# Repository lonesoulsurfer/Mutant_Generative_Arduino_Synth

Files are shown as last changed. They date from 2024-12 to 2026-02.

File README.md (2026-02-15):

# Mutant_Generative_Arduino_Synth



UPDATE: I have updated the Mutant code so it can be loaded using the most recent Mozzi Library.  You can find the code in the 'Mutant_Updated' file.  It works perfectly and there is no changes to the sounds etc.

 Meebleeps awesome Mutant Synth in modular format

First and foremost - I need to do a huge shoutout to MeeBleeps (https://github.com/Meebleeps/MeeBleeps-Mutant-Synth) who designed this amazing synth. I've designed a PCB and front panel to fit modular synths or you could use it as a stand alone synth if you wanted to.  You can power the synth used a voltage range from 9 to 12V's

You can find a step by step guide on my Instructables page on how to build your own - https://www.instructables.com/Mutant-Generative-Arduino-Synth/

I have also posted a video on my YouTube page - https://www.youtube.com/watch?v=L1Gzkz4_xpQ

The main goal with building this module is to create my own 'simple to build' modular synth. I wanted to keep everything as easy as possble with each module built with the following aims:

Can be powered by 9V (and 12V)
Easy to build with minimum components
Use Arduino to keep it simple (plus it helps to keep the components down and everything in tune)
Can fit into any modular synth Eurorck (include the ability to power the module via normal module power sources)
Has to sound great!
Lastly, it should be portable and be powered from a 9V battery

So what is the Mutant Synth? Well it's a generative synth based around a Arduino Nano and a handful of other components and produces a rich soundscape of sounds.

The synth voice is based around 2 saw oscillators that features:

Multiple tuning modes for the 2nd oscillator - off, detune, fifths & octaves up/down
Low pass filter with variable cutoff and resonance
Variable level ducking/sidechain effects
The display is a 8X8 LED matrix which allows you to visually see where each control level is at. This also includes a 16 step generative sequencer that mutates/evolves at defined rate depending on control inputs.

Variable sequence mutation probability & note-density
Sync input & output (Korg Volca compatible)
Note selection
Selectable scale quantization (Major, Minor, Pentatonic, Phrygian (GOA!), Octaves, Fifths)
16-step parameter-lock recording of synth parameters
Retrig (clone) button for different fills
Tap-tempo control

The Mozzi library used in the script is an older version which isn't a big deal but you will need to update IDE with an older version of Mozzie (1.1.2).  You can easily do this in IDE but if you are unsure how to do this then check out my Instruacable I published.



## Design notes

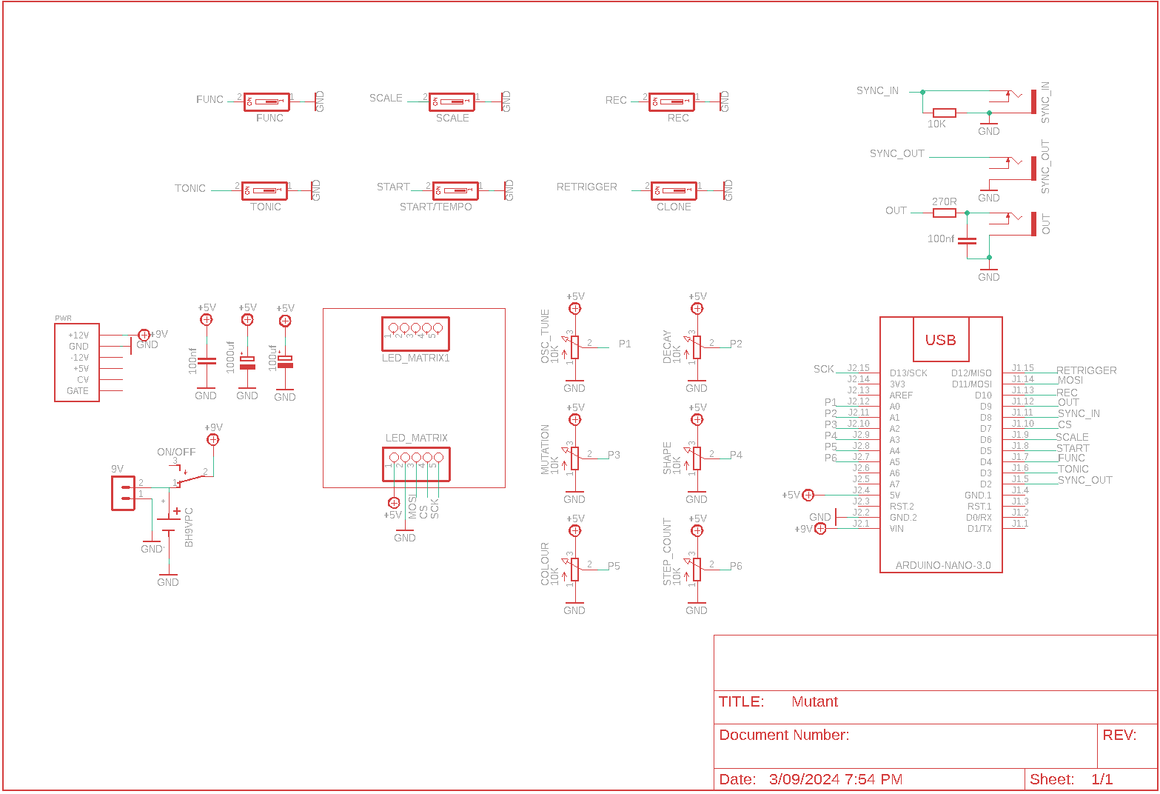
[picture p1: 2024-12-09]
Schematic.png

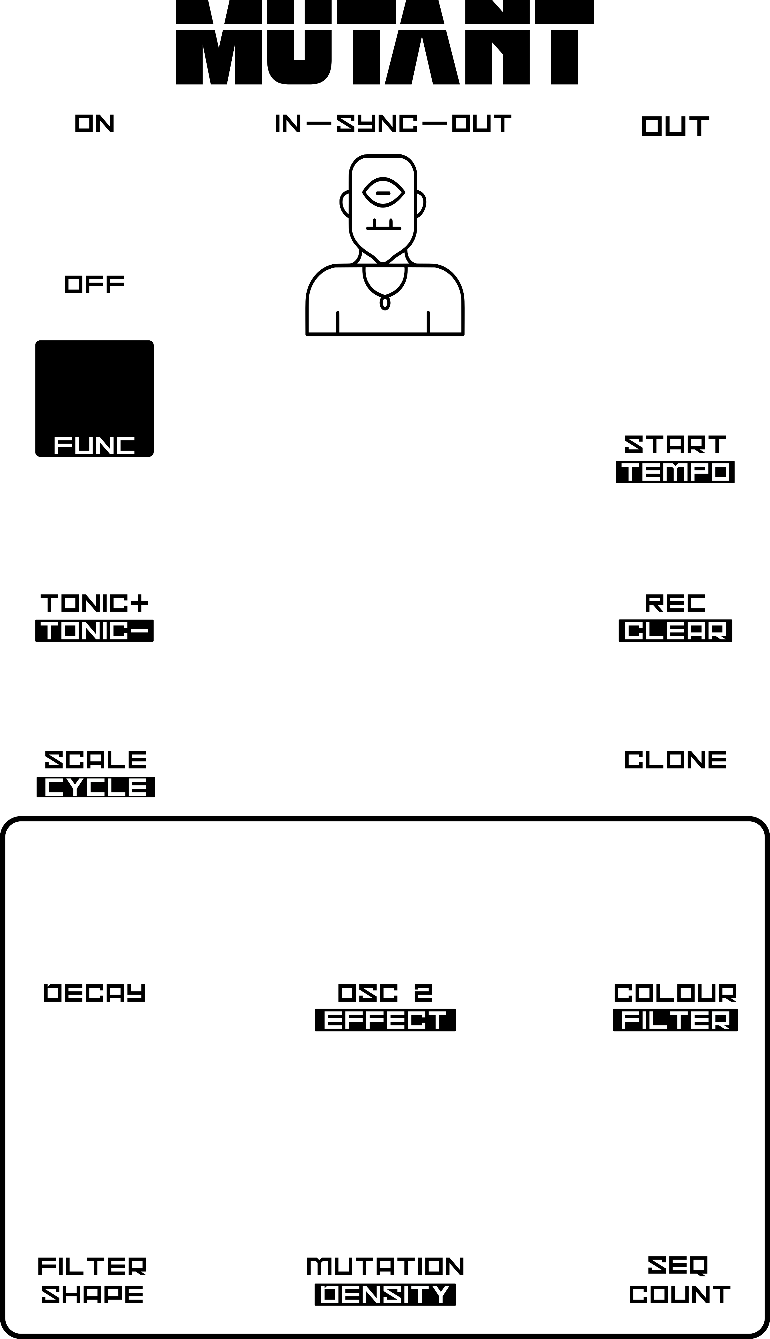
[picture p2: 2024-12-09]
Front Panel Design/mutant - front panel 2.png

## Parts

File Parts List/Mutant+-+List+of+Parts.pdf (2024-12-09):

Part Type Value Qty | Image | Link | Notes
9V Battery Holder 1 | | Link (https://vi.aliexpress.com/w/wholesale-9v-battery-holder-mount.html?spm=a2g0o.productlist.search.0) | Not needed if you plan to power via external connector. Make sure it has 2 legs to be able to mount & solder to the PCB

9V Battery 1

Capacitor Polypropylene 104J 100nf 2 | | Link (https://vi.aliexpress.com/w/wholesale-capacitor-100nf.html?spm=a2g0o.productlist.search.0)
100uf Capacitor Polarized esr 1000uf | | Link (https://vi.aliexpress.com/w/wholesale-capacitor-100uf-.html?spm=a2g0o.productlist.search.0) Link (https://vi.aliexpress.com/w/wholesale-capacitor-1000uf-esr.html?spm=a2g0o.productlist.search.0) | I like to use high frequency, low noise capacitors

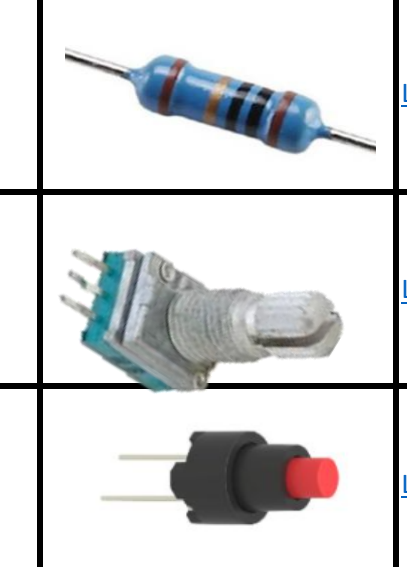
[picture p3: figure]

10K 1 Resistors Metal Film 1% 270R 1 | | Link (https://vi.aliexpress.com/w/wholesale-resistor-metal-film.html?spm=a2g0o.productlist.search.0)
Potentiometers 9mm Vertical 10K 6 | | Link (https://www.aliexpress.com/w/wholesale-9mm-vertical-potentiometer.html) | Use the metal sharft type. You can use the nut on these to help secure the front panel to the PCB
Momentary (PN SKRCADD010) 6 Switch On/Off Toggle Switch Through Hole version | | Link (https://www.aliexpress.com/w/wholesale-SKRCADD010.html?spm=a2g0o.productlist.search.0) Link (https://vi.aliexpress.com/item/1005001510219617.html) | Make sure that the pins on the switch are Stich pins and are able to go through the holes in the PBC
LED Dot Matrix TZT MAX7219 1 | | Link | Here is an exact link to the one that I used (https://vi.aliexpress.com/item/1005004118366858.html)
Female Header Pin Socket 15 Pin 2 | | Link (https://vi.aliexpress.com/w/wholesale-Single-Row-Female-2.54MM-Spacing-Pin.html) | These are used to hold the Arduino into place. You could solder the Arduino onto the PCB but be careful of shorts that may happen against the components on the other side
Arduino Nano 3 1 | | Link (https://vi.aliexpress.com/w/wholesale-arduino-nano.html?spm=a2g0o.detail.search.0)

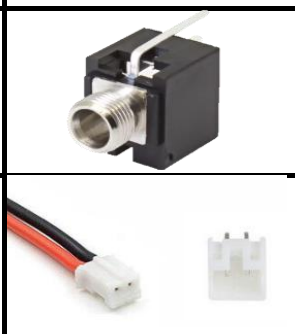
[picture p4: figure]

Audio Socket 3.5mm (PN - PJ-301M) 3 | | Link (https://vi.aliexpress.com/item/1005005352992401.html?scm_id=1007.40050.354490.0&scm-url=1007.40050.354490.0)
Mini JST Connector and wire 2 Pin 1 | | Link (https://vi.aliexpress.com/item/1005005939956886.html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) | This is used to either power the PCB or to test it. If you are going with the 9v battery then you could leave this

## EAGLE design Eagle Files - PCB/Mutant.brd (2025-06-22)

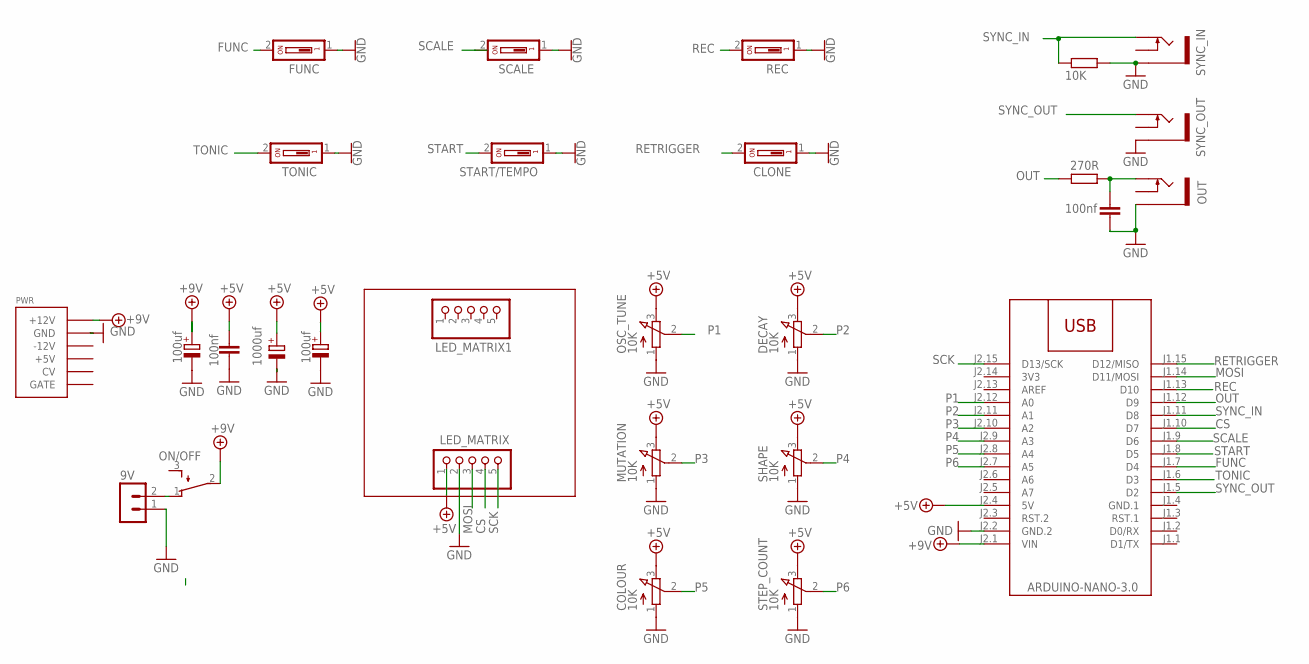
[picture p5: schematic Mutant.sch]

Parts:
9V: B2B-PH-K-S
C1, C4: 100nf; C050-024X044
C2, C3: 100uf; E2-5
C5: 1000uf; E2,5-6E
CLONE: DS01; DS-01
COLOUR: 10K; EVUFXL
DECAY: 10K; EVUFXL
FUNC: DS01; DS-01
LED_MATRIX, LED_MATRIX1: PINHD-1X5; 1X05
M1: ARDUINO-NANO-3.0
MUTATION: 10K; EVUFXL
ON/OFF: TL32PO; TL3XPO
OSC_TUNE: 10K; EVUFXL
OUT: THONKICONNNEW; WQP-PJ301M-12_JACK
PWR: POWER; POWER_16
R7: 10K; 0207/10
R8: 270R; 0207/10
REC: DS01; DS-01
SCALE: DS01; DS-01
SHAPE: 10K; EVUFXL
START/TEMPO: DS01; DS-01
STEP_COUNT: 10K; EVUFXL
SYNC_IN: THONKICONNNEW; WQP-PJ301M-12_JACK
SYNC_OUT: THONKICONNNEW; WQP-PJ301M-12_JACK
TONIC: DS01; DS-01

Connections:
3V3: M1.J2.14 (3V3)
+5V: C1.1, C2.+, C5.+, COLOUR.3 (E), DECAY.3 (E), LED_MATRIX.1, M1.J2.4 (5V), MUTATION.3 (E), OSC_TUNE.3 (E), SHAPE.3 (E), STEP_COUNT.3 (E)
+9V: C3.+, M1.J2.1 (VIN), ON/OFF.2, PWR.9 (+12V), PWR.10 (+12V)
CS: LED_MATRIX.4, M1.J1.10 (D7)
FUNC: FUNC.2, M1.J1.7 (D4)
GND: 9V.1, C1.2, C2.-, C3.-, C4.2, C5.-, CLONE.1, COLOUR.1 (A), DECAY.1 (A), FUNC.1, LED_MATRIX.2, M1.J2.2 (GND.2), MUTATION.1 (A), OSC_TUNE.1 (A), OUT.P$3_SLEEVE (SLEEVE), PWR.3 (GND), PWR.4 (GND), PWR.5 (GND), PWR.6 (GND), PWR.7 (GND), PWR.8 (GND), R7.2, REC.1, SCALE.1, SHAPE.1 (A), START/TEMPO.1, STEP_COUNT.1 (A), SYNC_IN.P$3_SLEEVE (SLEEVE), SYNC_OUT.P$3_SLEEVE (SLEEVE), TONIC.1
GND.1: M1.J1.4 (GND.1)
MOSI: LED_MATRIX.3, M1.J1.14 (D11/MOSI)
unnamed: 9V.2, ON/OFF.1 (O)
unnamed: C4.1, OUT.P$1_TIP (TIP), R8.2
OUT: M1.J1.12 (D9), R8.1
P1: M1.J2.12 (A0), OSC_TUNE.2 (S)
P2: DECAY.2 (S), M1.J2.11 (A1)
P3: M1.J2.10 (A2), MUTATION.2 (S)
P4: M1.J2.9 (A3), SHAPE.2 (S)
P5: COLOUR.2 (S), M1.J2.8 (A4)
P6: M1.J2.7 (A5), STEP_COUNT.2 (S)
REC: M1.J1.13 (D10), REC.2
RETRIGGER: CLONE.2, M1.J1.15 (D12/MISO)
SCALE: M1.J1.9 (D6), SCALE.2
SCK: LED_MATRIX.5, M1.J2.15 (D13/SCK)
START: M1.J1.8 (D5), START/TEMPO.2
SYNC_IN: M1.J1.11 (D8), R7.1, SYNC_IN.P$1_TIP (TIP)
SYNC_OUT: M1.J1.5 (D2), SYNC_OUT.P$1_TIP (TIP)
TONIC: M1.J1.6 (D3), TONIC.2

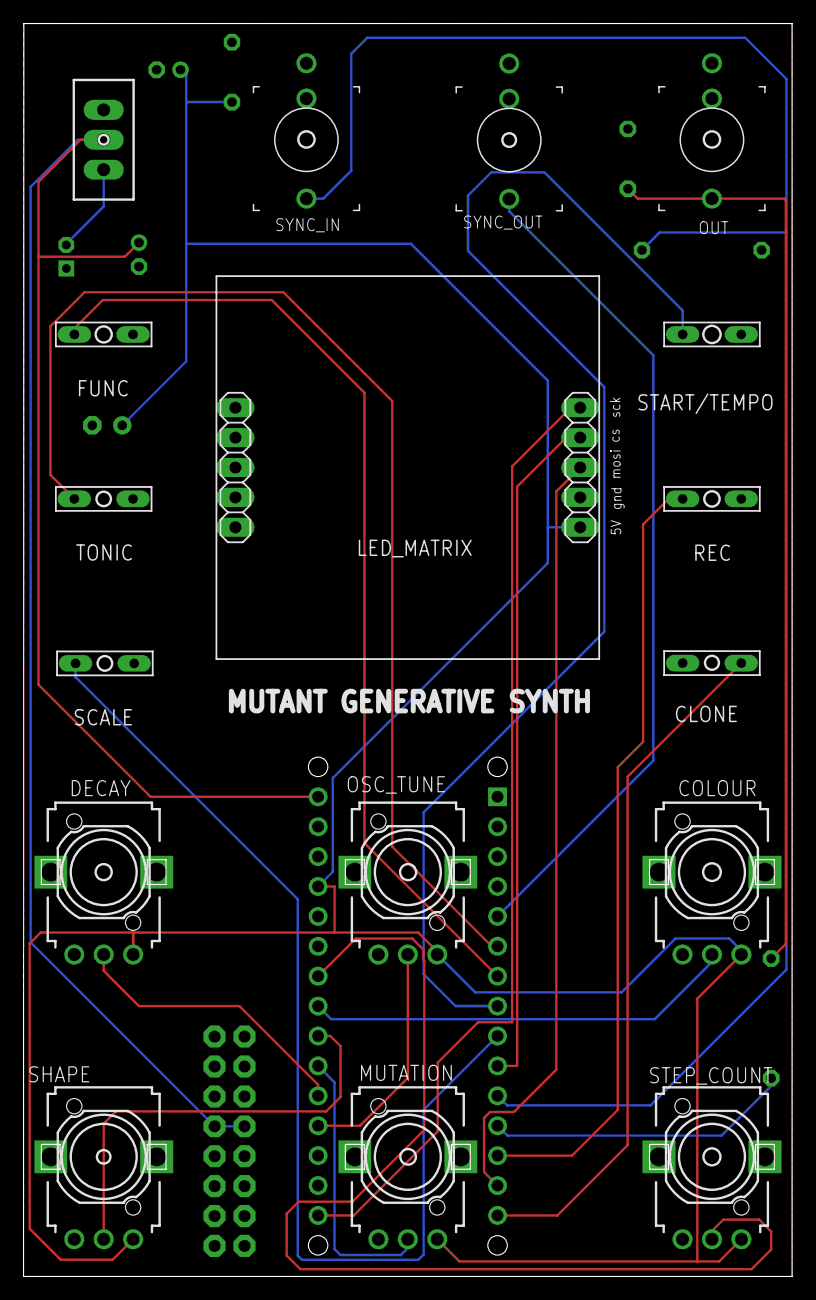
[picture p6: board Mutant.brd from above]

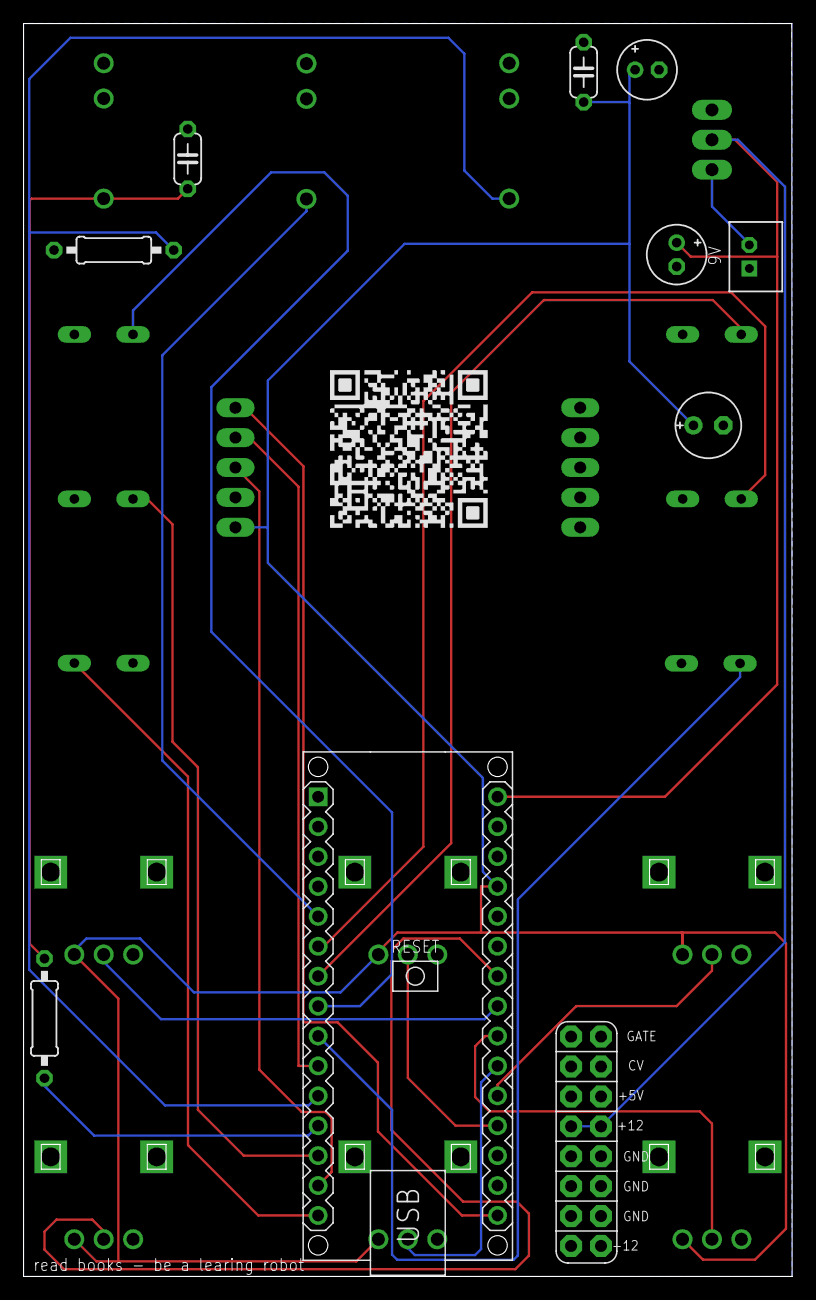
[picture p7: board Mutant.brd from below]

Board: 2 copper layers, 65.3 x 106.4 mm, 28 parts (10 on the bottom side), 23 nets.

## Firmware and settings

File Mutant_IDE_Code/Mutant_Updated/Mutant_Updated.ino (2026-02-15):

/*----------------------------------------------------------------------------------------------------------
 * MutantMozziSynth.ino
 * 
 * Main project file for the Mutant Mozzi Synth. 
 * 
 * Instantiates all mutant class objects 
 * Calls the Mozzi audio hook functions
 * manages the user interface
 * 
 * was originally developed in Arduino IDE before moving to VS Code
 * 
 * NOTE: This code has been updated to use the latest Mozzi 2.0+ library
 * 
 * (C) 2021 Meebleeps
*-----------------------------------------------------------------------------------------------------------
*/

#include <Arduino.h>

// Mozzi 2.0: Define control rate BEFORE including Mozzi.h
#define MOZZI_CONTROL_RATE 256
#include <Mozzi.h>

#include <mozzi_rand.h>
#include <EventDelay.h>

#include "avSource.h"
#include "avSequencer.h"
#include "LedMatrix.h"

// MOZZI variables - kept for reference (now using MOZZI_CONTROL_RATE above)
// #define CONTROL_RATE 256

// define the pins
#define PIN_SYNC_IN       8
#define PIN_SYNC_OUT      2
#define TIMER_SYNC_PULSE_OUTPUT_MILLIS 20

#define PIN_AUDIO_OUT     9
#define PIN_BUTTON0       4
#define PIN_BUTTON1       5
#define PIN_BUTTON2       6
#define PIN_BUTTON3       3
#define PIN_BUTTON4       10
#define PIN_BUTTON5       12
#define MAX_BUTTON_INPUTS 6


#define MAX_ANALOG_INPUTS               6
#define MAX_ANALOG_VALUE                1000

// these may change depending on how analog pots are wired up
#define ANALOG_INPUT_OSC2TUNE           0
#define ANALOG_INPUT_DECAY              1
#define ANALOG_INPUT_MUTATION           2
#define ANALOG_INPUT_FILTERSHAPE        3
#define ANALOG_INPUT_FILTER             4
#define ANALOG_INPUT_STEPCOUNT          5

// trial-and-error value to raise movement-detection above noise.  
//TODO: I'm sure there are libraries to do this!
#define ANALOG_INPUT_MOVEMENT_THRESHOLD 13

// listed in order of left to right.
#define BUTTON_INPUT_FUNC   0
#define BUTTON_INPUT_TONIC  3
#define BUTTON_INPUT_SCALE  2
#define BUTTON_INPUT_START  1
#define BUTTON_INPUT_REC    4  // D10 - Records pot movements (motion recording)
#define BUTTON_INPUT_RETRIG 5  // D12 - Clones/repeats note (retrigger function)


//#define MAX_OSCILLATOR_MODES 1

#define INTERFACE_MODE_NORMAL 0
#define INTERFACE_MODE_SHIFT  1

// some settings persist on-screen after being changed - for this many millis
#define DISPLAY_SETTING_CHANGE_PERSIST_MILLIS 500

// motion recordind mode, depending on whether the REC button is held with/without FUNC
#define MOTION_RECORD_NONE  0
#define MOTION_RECORD_REC   1
#define MOTION_RECORD_CLEAR 2

// decrease INTERFACE_UPDATE_DIVIDER  if controls are externally modulated via CV voltage inputs
#define INTERFACE_UPDATE_DIVIDER 4

//TODO: store these in PROGMEM instead of RAM
const byte BITMAP_MEEBLEEPS[]  = {B00011000,B01111110,B11011011,B11011011,B11011011,B11011011,B11000011,B00000110};
const byte BITMAP_NUMERALS[8][8]  = {
                                       {B00000000,B00000000,B00000000,B11100000,B10100000,B10100000,B10100000,B11100111}
                                      ,{B00000000,B00000000,B00000000,B01000000,B01000000,B01000000,B01000111,B01000000}
                                      ,{B00000000,B00000000,B00000000,B11100000,B00100000,B11100111,B10000000,B11100000}
                                      ,{B00000000,B00000000,B00000000,B11100000,B00100111,B11100000,B00100000,B11100000}
                                      ,{B00000000,B00000000,B00000000,B10100111,B10100000,B11100000,B00100000,B00100000}
                                      ,{B00000000,B00000000,B00000111,B11100000,B10000000,B11100000,B00100000,B11100000}
                                      ,{B00000000,B00000111,B00000000,B11100000,B10000000,B11100000,B10100000,B11100000}
                                      ,{B00000000,B00000111,B00000000,B11100000,B00100000,B00100000,B00100000,B00100000}
                                    };
const byte BITMAP_ALPHA[7][8]  = {
                                     {B00000000,B00000000,B00000000,B11100000,B10100000,B11100000,B10100000,B10100111}
                                    ,{B00000000,B00000000,B00000000,B11100000,B10100000,B11000000,B10100111,B11100000}
                                    ,{B00000000,B00000000,B00000000,B11100000,B10000000,B10000111,B10000000,B11100000}
                                    ,{B00000000,B00000000,B00000000,B11000000,B10100111,B10100000,B10100000,B11000000}
                                    ,{B00000000,B00000000,B00000000,B11100111,B10000000,B11000000,B10000000,B11100000}
                                    ,{B00000000,B00000000,B00000111,B11100000,B10000000,B11000000,B10000000,B10000000}
                                    ,{B00000000,B00000111,B00000000,B11100000,B10000000,B10000000,B10100000,B11100000}
                                  };
const byte BITMAP_ALGORITHMS[2][8]  = {
                                        {B01000001,B10010000,B00000100,B01010000,B01000010,B01001000,B01000001,B01000100}
                                      , {B00100001,B01000010,B00000100,B11101000,B00100000,B11100001,B10000010,B11100100}
                                      };
/* old bitmaps
const byte BITMAP_NUMERALS[8][8]  = {
                                      {B00111000,B01000100,B01000100,B01000100,B01000100,B01000100,B00111000,B00000000}
                                      ,{B00010000,B00110000,B00010000,B00010000,B00010000,B00010000,B00111000,B00000000}
                                      ,{B00111000,B01000100,B00000100,B00001000,B00010000,B00100000,B01111100,B00000000}
                                      ,{B00111000,B01000100,B00000100,B00011000,B00000100,B01000100,B00111000,B00000000}
                                      ,{B00001000,B00011000,B00101000,B01001000,B01111100,B00001000,B00001000,B00000000}
                                      ,{B01111100,B01000000,B01000000,B00111000,B00000100,B00000100,B01111000,B00000000}
                                      ,{B00111100,B01000000,B01000000,B00111000,B01000100,B01000100,B00111000,B00000000}
                                      ,{B00111000,B01000100,B01000100,B00111000,B01000100,B01000100,B00111000,B00000000}
                                    };
*/

/*
const byte BITMAP_ALPHA[7][8]  = {
                                       {B00111000,B01000100,B01000100,B01111100,B01000100,B01000100,B01000100,B00000000}
                                      ,{B01111000,B01000100,B01000100,B01111000,B01000100,B01000100,B01111000,B00000000}
                                      ,{B00111000,B01000100,B01000000,B01000000,B01000000,B01000100,B00111000,B00000000}
                                      ,{B01111000,B01000100,B01000100,B01000100,B01000100,B01000100,B01111000,B00000000}
                                      ,{B01111100,B01000000,B01000000,B01111000,B01000000,B01000000,B01111100,B00000000}
                                      ,{B01111100,B01000000,B01000000,B01111000,B01000000,B01000000,B01000000,B00000000}
                                      ,{B00111000,B01000100,B01000000,B01001100,B01000100,B01000100,B00111000,B00000000}
                                    };
*/

// when user presses start for the first time, do things like seed rand generator and clear screen
byte firstTimeStart   = true;

// state of sync trigger input pin
byte iTrigger         = 1;      
byte iLastTrigger     = 0;

// state of button input pins
byte iCurrentButton[MAX_BUTTON_INPUTS];
byte iLastButton[MAX_BUTTON_INPUTS];

// state of analog input pins
int iLastAnalogValue[6]    = {0,0,0,0,0,0};
int iCurrentAnalogValue[6] = {0,0,0,0,0,0};

// used during updateControl to reduce frequency of input control updates for efficiency
byte updateCounter    = 0;

// state of interface and motion control UI modifiers
byte interfaceMode    = INTERFACE_MODE_NORMAL;
byte motionRecordMode = MOTION_RECORD_NONE;

// a bitmap setting is being displayed
byte settingDisplayIconOn = false;

//TODO: this should probably be in the sequencer
uint8_t lastStepParameterLock[6] = {false,false,false,false,false,false};

// synth voice instance
MutatingPhasor    synthVoice;

// generative sequencer instance
MutatingSequencer sequencer;

// LED matrix instance.  probably could have used a standard MAX7219 library but was easy and enjoyable to make my own :)
LedMatrix         ledDisplay;

// timer to pull sync output low at the end of the pulse 
EventDelay        syncOutputTimer;
EventDelay        settingDisplayTimer;


/*----------------------------------------------------------------------------------------------------------
 * setup()
 *----------------------------------------------------------------------------------------------------------
 */
void setup() 
{
  Serial.begin(115200);
  Serial.print(F("\n\n\n\n\n-----------------------------------------------------------------------\n"));
  Serial.print(F("Mozzi-based Mutating Techno Synth.   Build "));
  Serial.print  (__DATE__);
  Serial.print  (F(" "));
  Serial.println  (__TIME__);

  initialisePins();
  initialiseDisplay();
  initialiseSources();
  initialiseSequencer();

  startMozzi();  // Mozzi 2.0: No parameter needed, uses MOZZI_CONTROL_RATE
}



/*----------------------------------------------------------------------------------------------------------
 * initialiseDisplay
 *----------------------------------------------------------------------------------------------------------
 */
void initialiseDisplay()
{
  ledDisplay.initialise();
  ledDisplay.setOrientation(LEDMATRIX_ORIENTATION_0);
  
  settingDisplayTimer.start(0);
  settingDisplayIconOn = false;

  // display logo intro
  for (int i=10; i< 100; i+=10)
  {
    ledDisplay.clearScreen();
    delay(i);
    ledDisplay.displayIcon(BITMAP_MEEBLEEPS);
    delay(i);
  }
  
  // fade
  for(int i = 15; i>= 0; i--)
  {
    ledDisplay.setIntensity(i);
    delay(20);
  }

  // set default brightness to 4 for normal use
  ledDisplay.setIntensity(4);
  ledDisplay.displayIcon(BITMAP_MEEBLEEPS);
}




/*----------------------------------------------------------------------------------------------------------
 * initialisePins
 *----------------------------------------------------------------------------------------------------------
 */
void initialisePins()
{
  Serial.println(F("initialisePins()"));


  pinMode(PIN_SYNC_OUT, OUTPUT);
  pinMode(PIN_SYNC_IN, INPUT);          // sync is pulled down by external pulldown resistor
  pinMode(PIN_BUTTON0, INPUT_PULLUP);   // all other buttons are pulled up by internal pullup resistor
  pinMode(PIN_BUTTON1, INPUT_PULLUP);
  pinMode(PIN_BUTTON2, INPUT_PULLUP);
  pinMode(PIN_BUTTON3, INPUT_PULLUP);
  pinMode(PIN_BUTTON4, INPUT_PULLUP);
  pinMode(PIN_BUTTON5, INPUT_PULLUP);

  pinMode(A0, INPUT);
  pinMode(A1, INPUT);
  pinMode(A2, INPUT);
  pinMode(A3, INPUT);
  pinMode(A4, INPUT);
  pinMode(A5, INPUT); 

  // initialise button state arrays
  for (int i = 0; i < MAX_BUTTON_INPUTS; i++)
  {
    iLastButton[i]    = 0;
    iCurrentButton[i] = 0;
  }

  for (int i = 0; i < MAX_ANALOG_INPUTS; i++)
  {
    iLastAnalogValue[i] = 0;
  }
}



/*----------------------------------------------------------------------------------------------------------
 * initialiseSources
 * Do anything necessary to initialise the synth voice/s that wasn't done in the constructor
 *----------------------------------------------------------------------------------------------------------
 */
void initialiseSources()
{
  
  //TODO: anything necessary to initialise the synth voice/s that wasn't done in the constructor
  
}



/*----------------------------------------------------------------------------------------------------------
 * initialiseSequencer
 * set the scalemode to minor and creates a new sequence
 *----------------------------------------------------------------------------------------------------------
 */
void initialiseSequencer()
{
  sequencer.setScale(SCALEMODE_MINOR);
  sequencer.newSequence(16);
  sequencer.setMutationProbability(100);  // Mutation fully on (100%)
  sequencer.setNoteProbability(100);      // Density fully on (100%)
}




/*----------------------------------------------------------------------------------------------------------
 * updateControl
 * called by Mozzi Library on CONTROL_RATE frequency
 * every INTERFACE_UPDATE_DIVIDER steps, check controls
 * every step - check for sync trigger and update sequencer
 * if this gets delayed, note on/off commands will drift
 *----------------------------------------------------------------------------------------------------------
 */
void updateControl()
{
  updateCounter++;

  // do this every time to ensure sync
  updateSyncTrigger();

  // check controls once every INTERFACE_UPDATE_DIVIDER steps for efficiency
  // todo:  decrease INTERFACE_UPDATE_DIVIDER  if these are externally modulated via CV voltage inputs
  if(updateCounter % INTERFACE_UPDATE_DIVIDER == 0)
  {

    // check button controls first to ensure interface mode is correctly set
    updateButtonControls();

    // now check analog controls
    updateAnalogControls();
  }

  // update sequencer every time to minimise latency
  // returns true if the seqeuncer has moved to next step
  if (updateSequencer())
  {
     //only update the display once per sequencer step    
     //TODO: this could be increased for more responsive display
    updateDisplay();
  }
  
  // check to see if the output sync pulse needs to be pulled low
  if (syncOutputTimer.ready())
  {
    digitalWrite(PIN_SYNC_OUT, LOW);
  }

  
  // now that all controls are updated, update the source.
  
  
  // sequencer sets the ducking amount based on internal envelope
  long duckingAmount = sequencer.getDuckingAmount();
  
  
  if (duckingAmount > 0)
  {
    long duckingGain;

    duckingGain = sequencer.getDuckingEnvelope();

    if (duckingGain < 250)
    {
      duckingGain = ((duckingGain*duckingAmount) >> 8) + (256-duckingAmount);
      
      // display the ducking gain reduction as a bar on the LED matrix
      ledDisplay.drawLineV(6, 0, 6,true);
      ledDisplay.drawLineV(6, 0, scaleAnalogInput( duckingGain*4,6),false);
    }
    else
    {
      duckingGain = 255;
    }
    
    synthVoice.setGain(duckingGain);
  }
  else
  {
    synthVoice.setGain(255);
  }

  synthVoice.updateControl();
}


/*----------------------------------------------------------------------------------------------------------
 * updateSequencer
 * returns true if sequencer advances to the next step
 *----------------------------------------------------------------------------------------------------------
 */
int updateSequencer()
{
  byte      nextNote;
  uint16_t  nextNoteLength;
  
  // if the sequencer is due to make a new step, 
  if (sequencer.update(false))
  {
    // if the sequencer is on an even step - output a sync pulse
    if (sequencer.outputSyncPulse())
    {
      outputSyncPulse();
    }
    
    nextNote        = sequencer.getCurrentNote();
    nextNoteLength  = sequencer.getNextNoteLength();
    
    if (nextNote > 0)
    {
      updateSequencerStepModulation();

      synthVoice.noteOn(nextNote, 255, nextNoteLength);
    }
    
    return true;
  }
  else
  {
    return false;
  }

  
}


/*----------------------------------------------------------------------------------------------------------
 * outputSyncPulse
 * sends a digital signal to the output pin and sets the timer to pull it low after TIMER_SYNC_PULSE_OUTPUT_MILLIS
 *----------------------------------------------------------------------------------------------------------
 */
void outputSyncPulse()
{
  syncOutputTimer.start(TIMER_SYNC_PULSE_OUTPUT_MILLIS);
  digitalWrite(PIN_SYNC_OUT,  HIGH);
}


/*----------------------------------------------------------------------------------------------------------
 * updateSequencerModulation
 * updates source parameters based on current control values or recorded motion (if any) 
 *----------------------------------------------------------------------------------------------------------
 */
void updateSequencerStepModulation()
{
 
  if (sequencer.getParameterLock(0) != 0)
  {
    sequencer.setNextNoteLength(sequencer.getParameterLock(0));
    lastStepParameterLock[0] = true;
  }
  else if (lastStepParameterLock[0])  // if the last step was parameter locked, then reset to the current knob position
  {
    updateNoteDecay(true);
    lastStepParameterLock[0] = false;
  }

  if (sequencer.getParameterLock(1) != 0)
  {
    synthVoice.setOscillatorDetune(sequencer.getParameterLock(1));
    lastStepParameterLock[1] = true;
  }
  else if (lastStepParameterLock[1])  // if the last step was parameter locked, then reset to the current knob position
  {
    updateOscillatorDetune(true);
    lastStepParameterLock[1] = false;
  }

  if (sequencer.getParameterLock(2) != 0)
  {
    synthVoice.setFilterCutoff(sequencer.getParameterLock(2));
    lastStepParameterLock[2] = true;
  }
  else if (lastStepParameterLock[2])  // if the last step was parameter locked, then reset to the current knob position
  {
    updateFilterCutoff(true);
    lastStepParameterLock[1] = false;
  }

  if (sequencer.getParameterLock(3) != 0)
  {
    synthVoice.setFilterResonance(sequencer.getParameterLock(3));
    lastStepParameterLock[3] = true;
  }
  else if (lastStepParameterLock[3])  // if the last step was parameter locked, then reset to the current knob position
  {
    updateFilterResonance(true);
    lastStepParameterLock[3] = false;
  }

  if (sequencer.getParameterLock(4) != 0)
  {
    synthVoice.setFilterShape(sequencer.getParameterLock(4));
    lastStepParameterLock[4] = true;    
  }
  else if (lastStepParameterLock[4])  // if the last step was parameter locked, then reset to the current knob position
  {
    updateFilterShape(true);
    lastStepParameterLock[4] = false;
  }
}




/*----------------------------------------------------------------------------------------------------------
 * updateSyncTrigger
 * check for sync trigger and update sequencer
 *----------------------------------------------------------------------------------------------------------
 */
void updateSyncTrigger()
{
  iTrigger = digitalRead(PIN_SYNC_IN);   // read the sync pin

  if (iTrigger != iLastTrigger)
  {
    digitalWrite(PIN_SYNC_OUT, iTrigger);
    
    //trigger note on or off
    if (iTrigger == HIGH)
    {
      //Serial.println("sync!");
      sequencer.syncPulse(SYNC_STEPS_PER_PULSE);
    }

    iLastTrigger = iTrigger;
  }
}
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
void loop() 
{
  //required for Mozzi
  audioHook();
}

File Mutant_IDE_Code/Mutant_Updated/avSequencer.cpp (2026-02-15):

/*----------------------------------------------------------------------------------------------------------
 * avSequencer.cpp
 * 
 * Implements a generative sequencer with multiple generative algorithms, musical scale quantisation,
 * variable sequence length (up to 16 steps) and multiple parameter-lock (motion-sequencing) channels
 * 
 * (C) 2021 Meebleeps
*-----------------------------------------------------------------------------------------------------------
*/
#include "Arduino.h"
#include "avSequencer.h"

// Mozzi 2.0: Include MozziHeadersOnly for access to Mozzi functions
#include <MozziHeadersOnly.h>
#include <mozzi_rand.h>

/*----------------------------------------------------------------------------------------------------------
 * MutatingSequencer::MutatingSequencer()
 * initialises the sequencer
 *----------------------------------------------------------------------------------------------------------
 */
MutatingSequencer::MutatingSequencer()
{
  running             = false;
  mutationAlgorithm   = MUTATE_ALGO_DEFAULT;

  // initialise sequence
  for (int i = 0; i < MAX_SEQUENCE_LENGTH; i++)
  {
    notes[i] = 0;
  }
  
  for (int i = 0; i < MAX_SCALE_LENGTH; i++)
  {
    scaleNotes[i] = 0;
  }

  for (int i = 0; i < MAX_SEQUENCE_LENGTH; i++)
  {
    for (int m = 0; m < 6; m++)
    {
      parameterLocks[m][i] = 0;
    }
  }

  currentStep         = 0;  
  retrigStep          = 0;     
  retrigState         = false;                        
  tonicNote           = 33;   // default to A2                           
  mutationProbability = 0;
  noteProbability      = 70;
  tonicProbability    = 30;
  rachetProbability   = 30;
  scatterProbability  = 0;
  shufflePct          = 50;
  sequenceLength      = 16;
  bpm                 = 130;
  currentNote         = tonicNote;
  nextStepNoteLength  = 80;
  octaveSpread        = 3;  
  scaleNoteCount      = 7;

  // deleted this to allow for different pulse steps defined by the UI layer
  //syncPulseSteps        = 2;      // standard 2 steps per sync pulse as per volca
  syncPulseClockDivide  = 1;      // divide the clock by this many steps
  
  nextStepTimeMillis  = (15000 / bpm); // 16th note length for given BPM
  
  lastSyncPulseTimeMicros = 0;
  
  initialiseScale(SCALEMODE_PENTA);
  newSequence(sequenceLength);

  duckingEnvelope.setTimes(80,1000,1000,5);
  duckingEnvelope.setADLevels(0,255);
  duckingCounter = 0;

  _debugOutput        = true;
  printParameters();
}



/*----------------------------------------------------------------------------------------------------------
 * MutatingSequencer::start()
 * starts the sequencer at step 0
 *----------------------------------------------------------------------------------------------------------
 */
void MutatingSequencer::start()
{
  Serial.println(F("Sequencer.Start()"));
  running             = true;
  ignoreNextSyncPulse = true;
  //nextStep(true);
}




/*----------------------------------------------------------------------------------------------------------
 * MutatingSequencer::stop()
 * stops the sequencer
 *----------------------------------------------------------------------------------------------------------
 */
void MutatingSequencer::stop()
{
  Serial.println(F("Sequencer.Stop()"));

  running = false;
}


/*----------------------------------------------------------------------------------------------------------
 * MutatingSequencer::toggleStart()
 * starts the sequencer if it is stopped, otherwise stops it
 *----------------------------------------------------------------------------------------------------------
 */
void MutatingSequencer::toggleStart()
{
  if (!running)
  {
    start();
  }
  else
  {
    stop();  
  }
}



/*----------------------------------------------------------------------------------------------------------
 * MutatingSequencer::setScale()
 * sets the scale and generates a new sequence according to the new scale
 *----------------------------------------------------------------------------------------------------------
 */
 void MutatingSequencer::setScale(uint8_t scaleMode)
{
  initialiseScale(scaleMode);
  newSequence(sequenceLength);
  Serial.print("NEW SCALE: ");
  Serial.println(scaleMode);
}


/*----------------------------------------------------------------------------------------------------------
 * MutatingSequencer::getScale()
 * returns the current scale mode
 *----------------------------------------------------------------------------------------------------------
 */
 uint8_t MutatingSequencer::getScale()
{
  return currentScaleMode;
}


/*----------------------------------------------------------------------------------------------------------
 * MutatingSequencer::getAlgorithm()
 * returns the current mutation algorithm
 *----------------------------------------------------------------------------------------------------------
 */
uint8_t MutatingSequencer::getAlgorithm()
{
  return mutationAlgorithm;
}


/*----------------------------------------------------------------------------------------------------------
 * MutatingSequencer::setAlgorithm()
 * sets the current mutation algorithm
 *----------------------------------------------------------------------------------------------------------
 */
void MutatingSequencer::setAlgorithm(uint8_t newValue)
{
  mutationAlgorithm = newValue % MAX_MUTATE_ALGO_COUNT;
}

/*----------------------------------------------------------------------------------------------------------
 * MutatingSequencer::incrAlgorithm()
 * moves to the next algorithm
 *----------------------------------------------------------------------------------------------------------
 */
void MutatingSequencer::nextAlgorithm()
{
  mutationAlgorithm = (mutationAlgorithm + 1) % MAX_MUTATE_ALGO_COUNT;
  Serial.print(F("New Algorithm = "));
  Serial.println(mutationAlgorithm);
}




/*----------------------------------------------------------------------------------------------------------
 * MutatingSequencer::getCurrentNote()
 * gets the note value for the current step
 *----------------------------------------------------------------------------------------------------------
 */
byte MutatingSequencer::getCurrentNote()
{
  if (!retrigState)
  {
    return notes[currentStep];
  }
  else
  {
    return notes[retrigStep];
  }
}


/*----------------------------------------------------------------------------------------------------------
 * MutatingSequencer::getCurrentStep()
 * gets  the current playing step
 *----------------------------------------------------------------------------------------------------------
 */
byte MutatingSequencer::getCurrentStep()
{
  if(!retrigState)
  {
    return currentStep;
  }
  else
  {
    return retrigStep;
  }
  
}
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

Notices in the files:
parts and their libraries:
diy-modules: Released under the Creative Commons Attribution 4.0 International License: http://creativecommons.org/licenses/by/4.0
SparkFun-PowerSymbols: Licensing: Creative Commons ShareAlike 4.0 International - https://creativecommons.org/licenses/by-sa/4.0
